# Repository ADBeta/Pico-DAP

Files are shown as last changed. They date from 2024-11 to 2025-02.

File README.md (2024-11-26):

# Pico-DAP
Pico-DAP is a CMSIS-DAP and Virtual COM Port (VCP) Device for programming
ARM based Microcontrollers, based on the `RP2040` Raspberry Pi Pico 
architecture, using the Pico-SDK toolchain.  

This reason for this project is to perfect the CMSIS-DAP device handling for
one specific device, without the worry of porting in the future.  
The project is open to the community and any ideas you have.  

## Flashing
`pico-dap.bin` and `pico-dap.uf2` files are available in the 
[Binaries](/Firmware/bins) directory.  
Use the `.uf2` if you are flashing via USB bootloader, or `.bin` if you are 
flashing via SWD.

## PCBs
### Pico-DAP-Zero
The original PCB for this project, using an aftermarket Pico Zero Development
board  
<div style="display: flex; align-items: center; gap: 10px;">
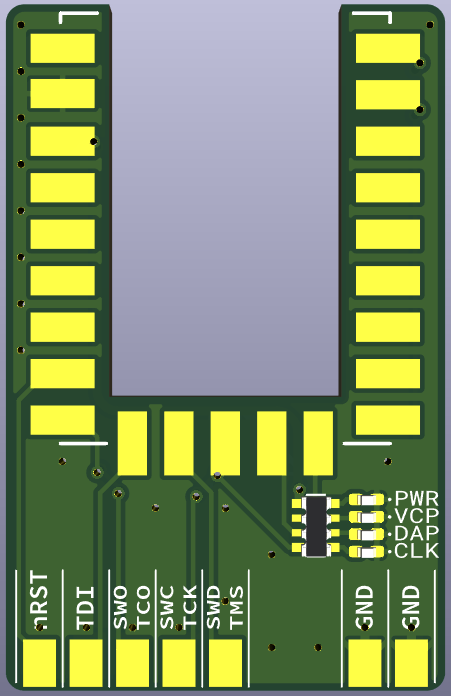
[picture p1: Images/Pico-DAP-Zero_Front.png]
Pico-DAP-Zero_Front
  
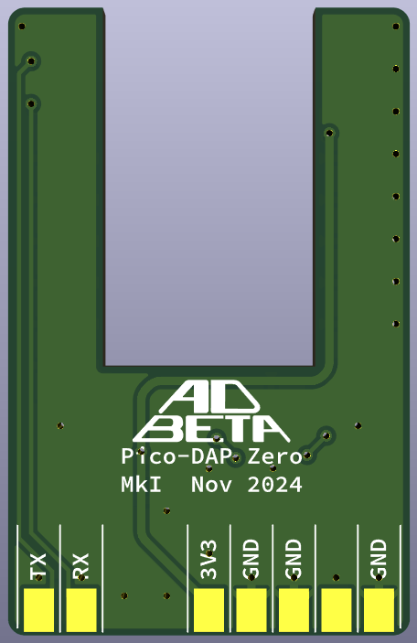
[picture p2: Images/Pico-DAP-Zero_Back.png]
Pico-DAP-Zero_Back
  
</div>

## TODO
* Move free-dap to a Pico-SDK Project
* Make a PCB for the regular Pico
* Make a PCB for a bare RP2040
* Change USB VID and PID

## Possible Changes
* Add CH32V SWIO Support
* Make specific JTAG USB Adatper

----
ADBeta (c) 2024

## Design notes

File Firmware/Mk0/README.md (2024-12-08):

# Original Firmware
This firmware is based on [free-dap](https://github.com/ataradov/free-dap), 
written by [Alex Taradov](https://github.com/ataradov).  

The only modifications made are:  
* Change VCP and DAP Status LED Pins
* Change USB Descriptor strings
* Changed Makefile to produce `pico-dap` files instead of `free-dap`

## Compilation
```sh
cd ./make
make
```
`pico-dap.uf2`and `pico-dap.bin` should be in the `/make/build/` directory

## Note
I plan on porting this firmware to be fully compatable with the Pico-SDK
for easier compilation and community modification in the near future.  
This README will be updated as progress is made

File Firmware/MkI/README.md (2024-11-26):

# Pico-DAP Firmware
This firmware is based on [free-dap](https://github.com/ataradov/free-dap), 
written by [Alex Taradov](https://github.com/ataradov).  
Converted into a Pico-SDK Project, with changes and improvements.

## Binary files
`pico-dap.bin` and `pico-dap.uf2` are available in the [Binary](/Firmware/bins) 
directory for easy installation.

## Compilation
You will need to install [Pico-SDK](https://www.raspberrypi.com/documentation/microcontrollers/c_sdk.html)
and Optionally [picotool](https://github.com/raspberrypi/picotool) in order to compile this firmware.  
```sh
mkdir ./build
cd ./build
cmake ..
make
```
`pico-dap.bin` and `pico-dap.uf2` files should now be in the `build` directroy

## Changelog
* Changed USB Device Descriptors
* Changed VID PID for USB
* Changed VCP and DAP Status LEDs

## TODO
### HIGH PRIORITY
* Convert all IO Calls to remove hal files
* Convert all uart calls to remove uart.c/.h
* Convert fully from rp2040.h to pico-stdlib

### MEDIUM PRIORITY
* make tasks.c/.h to tidy up main task handing

### LOW PRIORITY

----
ADBeta (c) 2024

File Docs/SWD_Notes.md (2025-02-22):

# CMSIS-DAP / DAP / SWD notes

## Nodes
Communication is over one generic bus : DAP `Debug Access Port`  
Master device is DP `Debug Port`  
Slave Device(s) are AP `Access Ports`  
Packets are sent from the `DP` to the `AP`. The Packets contain the Address  

Comms can be done over `JTAG`, `AHB` and `APB`:
* JTAG
* AHB
* APB

## Port types
* JTAG     (Uses JTAG Protocol)
* SW-DP    (Uses SWD specifically)
* SWJ-DP   (Uses JTAG Or SWD)

Memory access and JTAG access are possible depending on need

## Hardware Protocol
- SWCLK - Max 60MHz clock signal
- SwDIO - Bidirectional data signal - SET by `DP` on Rising Edge, Read by `DP` on falling edge
```
RQST Phase:    8 bit          [Start (1)] [AP(1)/DP(0)] [R(1)/W(0)] [AP/DP ADDR][AP/DP ADDR] [Odd Parity] [Stop (0)] [Park (1)]
ACK Phase:     3 bit          [OK]  [WAIT (Retry)] [FAULT]
DATA Phase:    32 bit         LSB First
PARITY:        1 bit odd

Extra Trn clock cycle when DDR Changes
```

## Registers
```
0x00

0x04    CTRL/STAT
0x0C    RDBUFF
```

## Init Procedure
**Switching from JTAG to DAP**  
1) Send 50 CLK Cycles with SWDIO HIGH
2) Send 16-bit JTAG->SWD Sequence
3) Send 50 CLK Cycles with SWDIO HIGH
`0b0111 1001 1110 0111`

**Read Debug Identity**  
Read Register 0x00 on DP  
`0xA5` `0x00000000 READ`

**Power up Debug Domain**  
Set CDBGRSTREQ and CDBGRSTACK Bits in CTRL/STAT Address  
`0x81` `0x1E000000 WRITE` NOTE: Why is this 1E when bit 28 29 set????

## Read from AP
`DP (master)` must send 

## Function Ideas
Init function sends multiple bytes of 0xFF

Struct packed with bit structure
read/write functions are calls to a generic backend function
Functions return ack bits as an enum type

## DAP HID Protocol
### Commands
```
0x00    DAP_Info                Requests ID from the DAP Device
0x01    DAP_HostStatus          Sets the host status (e.g., LED indicators)
0x02    DAP_Connect             Connects to the debug target (SWD or JTAG)
0x03    DAP_Disconnect          Disconnects from the debug target
0x04    DAP_TransferConfigure   Configures SWD/JTAG transfer settings
0x05    DAP_Transfer            Performs a single or multiple SWD/JTAG transfers
0x06    DAP_TransferBlock       Performs a block transfer over SWD/JTAG
0x07    DAP_TransferAbort       Aborts an ongoing SWD/JTAG transfer
0x08    DAP_WriteABORT          Writes to the Debug Port (DP) Abort register
0x09    DAP_Delay               Inserts a delay (in microseconds)

0x12	DAP_SWO_Transport       Selects SWO transport protocol
0x13	DAP_SWO_Mode            Configures the SWO mode
0x14	DAP_SWO_Baudrate        Sets the SWO baud rate
0x15	DAP_SWO_Control         Controls SWO trace capture
0x16	DAP_SWO_Status          Gets the status of SWO trace

0x0A    DAP_ResetTarget         Asserts a hardware reset on the target
0x0B    DAP_SWJ_Pins            Controls SWD/JTAG pins
0x0C    DAP_SWJ_Clock           Sets the SWD/JTAG clock frequency
0x0D    DAP_SWJ_Sequence        Sends a sequence of SWD/JTAG bits
0x0E    DAP_SWD_Configure       Configures the SWD interface
0x0F    DAP_JTAG_Sequence       Sends JTAG scan chain sequences
0x10    DAP_JTAG_Configure      Configures JTAG scan chain settings
0x11    DAP_JTAG_IDCODE         Reads the JTAG IDCODE

0x17    DAP_SWO_CaptureStart    Starts SWO trace capture
0x18    DAP_SWO_CaptureStop     Stops SWO trace capture
0x19    DAP_SWO_Read            Reads available SWO trace data

0xFF    DAP_Unknown             Placeholder for unknown or invalid command
```

----
ADBeta (c) 2025

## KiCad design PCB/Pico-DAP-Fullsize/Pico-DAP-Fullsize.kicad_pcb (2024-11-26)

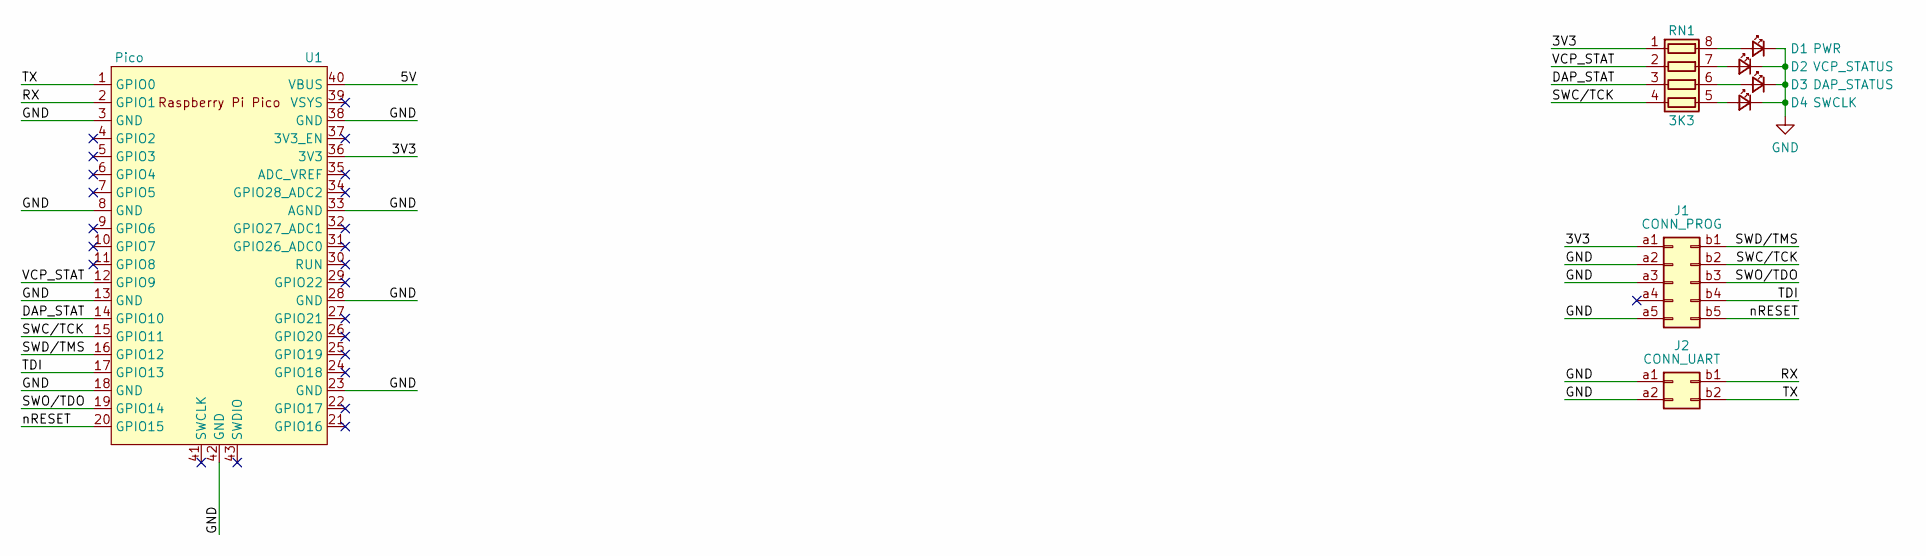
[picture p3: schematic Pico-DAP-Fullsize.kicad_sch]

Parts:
D1: PWR; LED_0402_1005Metric_Pad0.77x0.64mm_HandSolder
D2: VCP_STATUS; LED_0402_1005Metric_Pad0.77x0.64mm_HandSolder
D3: DAP_STATUS; LED_0402_1005Metric_Pad0.77x0.64mm_HandSolder
D4: SWCLK; LED_0402_1005Metric_Pad0.77x0.64mm_HandSolder
J1: CONN_PROG; Conn_2x5_Dual_Side
J2: CONN_UART; Conn_2x2_Dual_Side
RN1: 3K3; R_Array_Convex_4x0603
U1: Pico; RPi_Pico_SMD_TH

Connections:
/3V3: J1.a1, RN1.1 (R1.1), U1.36 (3V3)
/5V: U1.40 (VBUS)
/DAP_STAT: RN1.3 (R3.1), U1.14 (GPIO10)
/RX: J2.b1, U1.2 (GPIO1)
/SWC/TCK: J1.b2, RN1.4 (R4.1), U1.15 (GPIO11)
/SWD/TMS: J1.b1, U1.16 (GPIO12)
/SWO/TDO: J1.b3, U1.19 (GPIO14)
/TDI: J1.b4, U1.17 (GPIO13)
/TX: J2.b2, U1.1 (GPIO0)
/VCP_STAT: RN1.2 (R2.1), U1.12 (GPIO9)
/nRESET: J1.b5, U1.20 (GPIO15)
GND: D1.1 (K), D2.1 (K), D3.1 (K), D4.1 (K), J1.a2, J1.a3, J1.a5, J2.a1, J2.a2, U1.3 (GND), U1.8 (GND), U1.13 (GND), U1.18 (GND), U1.23 (GND), U1.28 (GND), U1.33 (AGND), U1.38 (GND), U1.42 (GND)
unnamed: D1.2 (A), RN1.8 (R1.2)
unnamed: D2.2 (A), RN1.7 (R2.2)
unnamed: D3.2 (A), RN1.6 (R3.2)
unnamed: D4.2 (A), RN1.5 (R4.2)

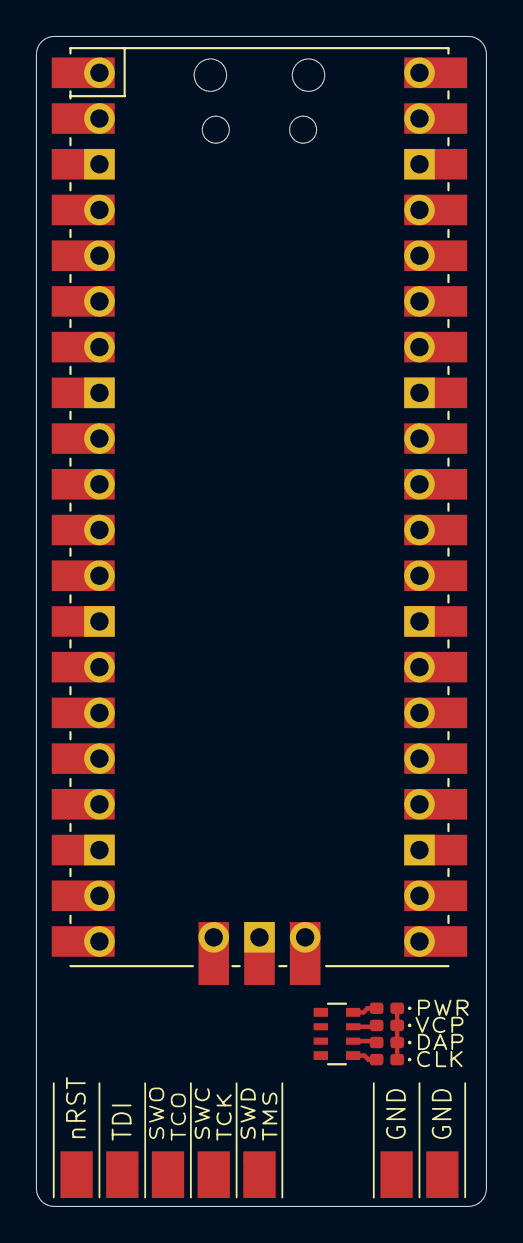
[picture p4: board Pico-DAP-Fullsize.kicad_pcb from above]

Board: 2 copper layers, 25.0 x 65.0 mm, 8 parts (1 on the bottom side), 15 nets.

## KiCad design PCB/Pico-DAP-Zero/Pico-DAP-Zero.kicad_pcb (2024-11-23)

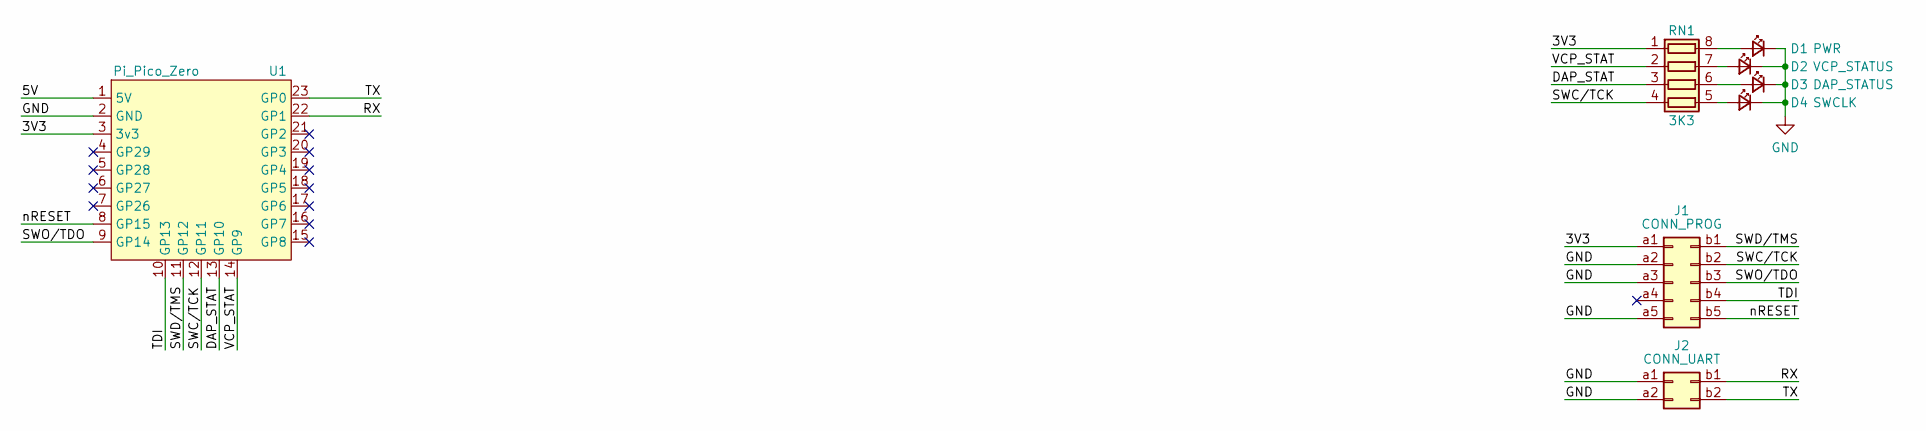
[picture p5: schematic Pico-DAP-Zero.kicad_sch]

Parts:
D1: PWR; LED_0402_1005Metric_Pad0.77x0.64mm_HandSolder
D2: VCP_STATUS; LED_0402_1005Metric_Pad0.77x0.64mm_HandSolder
D3: DAP_STATUS; LED_0402_1005Metric_Pad0.77x0.64mm_HandSolder
D4: SWCLK; LED_0402_1005Metric_Pad0.77x0.64mm_HandSolder
J1: CONN_PROG; Conn_2x5_Dual_Side
J2: CONN_UART; Conn_2x2_Dual_Side
RN1: 3K3; R_Array_Convex_4x0603
U1: Pi_Pico_Zero; Pi_Pico_Zero_Center_Hole

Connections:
/3V3: J1.a1, RN1.1 (R1.1), U1.3 (3v3)
/5V: U1.1 (5V)
/DAP_STAT: RN1.3 (R3.1), U1.13 (GP10)
/RX: J2.b1, U1.22 (GP1)
/SWC/TCK: J1.b2, RN1.4 (R4.1), U1.12 (GP11)
/SWD/TMS: J1.b1, U1.11 (GP12)
/SWO/TDO: J1.b3, U1.9 (GP14)
/TDI: J1.b4, U1.10 (GP13)
/TX: J2.b2, U1.23 (GP0)
/VCP_STAT: RN1.2 (R2.1), U1.14 (GP9)
/nRESET: J1.b5, U1.8 (GP15)
GND: D1.1 (K), D2.1 (K), D3.1 (K), D4.1 (K), J1.a2, J1.a3, J1.a5, J2.a1, J2.a2, U1.2 (GND)
unnamed: D1.2 (A), RN1.8 (R1.2)
unnamed: D2.2 (A), RN1.7 (R2.2)
unnamed: D3.2 (A), RN1.6 (R3.2)
unnamed: D4.2 (A), RN1.5 (R4.2)

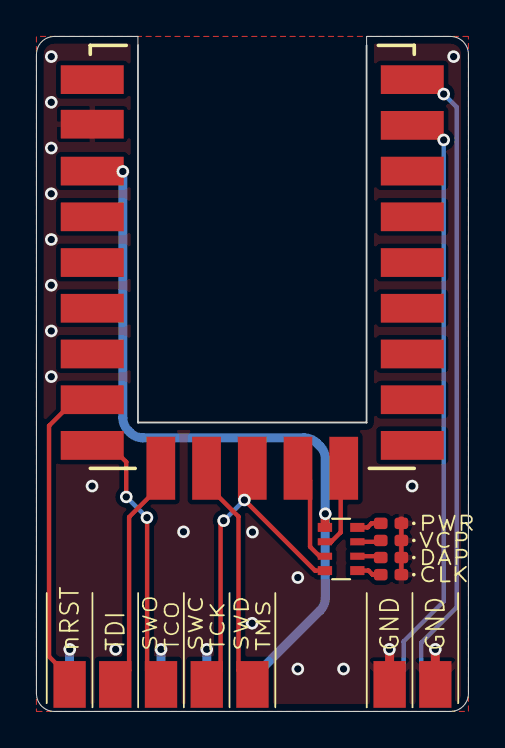
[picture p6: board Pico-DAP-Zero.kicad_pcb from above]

Board: 2 copper layers, 24.0 x 37.5 mm, 8 parts (1 on the bottom side), 15 nets.

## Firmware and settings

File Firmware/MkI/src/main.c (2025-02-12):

/******************************************************************************
* Pico-DAP MkI
* Raspberry Pi Pico based CMSIS-DAP and UART Combo USB Device
* Based on the principals of free-dap:
* 	Copyright (c) 2022, Alex Taradov <alex@taradov.com>. All rights reserved.
*
* Pico-DAP is a total rewrite, focussing on the RP2040 Chip, 
* i.e Raspberry Pi Pico:
* 	Copyright (c) 2025, ADBeta
*
* Any parts of Pico-DAP used directly from free-dap will retain their original
* Copyright strings.
*
* 10 Feb 2025    V0.2.0
******************************************************************************/
#include <stdlib.h>
#include <stdint.h>
#include <stdbool.h>
#include <string.h>




#include "pico/stdlib.h"
#include "hardware/clocks.h"
#include "hardware/pll.h"
#include "hardware/uart.h"

#include "pin_config.h"

#include "bsp/board_api.h"
#include "tusb.h"

/*** Definitions *************************************************************/
// UART and CDC Buffer Size - The Hardware UART FIFO is 32Bytes, so this is 
// the limiting factor - could add a UART IRQ and a Ring Buffer if needed.
#define CDC_BUFFER_SIZE    64
#define UART_BUFFER_SIZE   64

// Timing Millisecond Values
#define MILLIS_USB         10
#define MILLIS_LED         500

/*** Enums and Types *********************************************************/


/*** Globals *****************************************************************/
// Current Milliseconds - Updated by a systick
volatile uint32_t g_current_millis = 0;

/*** Function Declarations ***************************************************/
/// @brief USB CDC Task that run in an infinite loop - pushes data back and 
/// forth from CDC to UART
/// @param None
/// @return None
void cdc_uart_task(void);

/// @brief Handles the LEDs based on system status
/// @param None
/// @return None
void led_task(void);





/*** Callback Functions ******************************************************/
/// @brief Sets the UART baudrate dependinging on what thr USB CDC Device
/// requested
void tud_cdc_line_coding_cb(uint8_t itf, cdc_line_coding_t const* p_line_coding) 
{
	uart_set_baudrate(PERIPH_UART_ID, p_line_coding->bit_rate);
}


/// @breif ticks once per Millisecond and incriments the global counter
bool ms_timer_callback(__unused struct repeating_timer *t)
{
	g_current_millis++;
	return true;
}



/*** Function Declarations ***************************************************/
/// @brief Initalises the GPIO modes, startup states, etc
/// @param None
/// @return None
static void gpio_setup(void);


/*** Main ********************************************************************/
int main(void)
{
	// Set up a 1ms timer
	struct repeating_timer ms_timer;
    add_repeating_timer_ms(1, ms_timer_callback, NULL, &ms_timer);
	
	// TinyUSB Setup - Config the USB Handler to the Board, then initialise
	// the TinyUSB system
	board_init();
	tud_init(BOARD_TUD_RHPORT);


	// TODO: HID Init???

	// Initialise the LED and UART GPIO
	gpio_setup();

	// Initialise the UART Hardware
	uart_init(PERIPH_UART_ID, 9600);                                           // Initialise the UART Peripheral with a basic baudrate
	uart_set_hw_flow(PERIPH_UART_ID, false, false);                            // Disable flow control
	uart_set_format(PERIPH_UART_ID, 8, 1, UART_PARITY_NONE);                   // Set Data its, Stop Bits and ParityUART_PARITY_NONE
	uart_set_fifo_enabled(PERIPH_UART_ID, true);                               // Enable FIFO buffering of UART



	// Loop Timing Variables
	static uint32_t prev_usb_millis = 0;
	static uint32_t prev_led_millis = 0;

	// Start Infinite loop
	while(true)
	{

		if(g_current_millis - prev_usb_millis > MILLIS_USB)
		{
			tud_task();
			cdc_uart_task();
			prev_usb_millis = g_current_millis;
		}


		if(g_current_millis - prev_led_millis > MILLIS_LED)
		{
			led_task();
			prev_led_millis = g_current_millis;
		}
		
	} // End Inifinite loop



	/*
	while(1)
	{
		sys_time_task();
		usb_task();
		tx_task();
		rx_task();
		break_task();
		uart_timer_task();
		status_timer_task();
	}

	*/



	return 0;
}

/*** Function Definitions ****************************************************/
static void gpio_setup(void)
{
	gpio_init(PIN_LED_TEST);
	gpio_init(PIN_LED_UART);
	gpio_init(PIN_LED_DAP);

	gpio_set_dir(PIN_LED_TEST, GPIO_OUT);
	gpio_set_dir(PIN_LED_UART, GPIO_OUT);
	gpio_set_dir(PIN_LED_DAP, GPIO_OUT);

	// Set UART Pins
	gpio_set_function(PIN_UART_TX, UART_FUNCSEL_NUM(PERIPH_UART_ID, PIN_UART_TX));
	gpio_set_function(PIN_UART_RX, UART_FUNCSEL_NUM(PERIPH_UART_ID, PIN_UART_RX));
}


void cdc_uart_task(void)
{
	static uint8_t cdc_buff[CDC_BUFFER_SIZE];
	static uint8_t uart_buff[UART_BUFFER_SIZE];
	// If data is available in the UART, pull it into the buffer, then
	// push it out to the CDC Device
	size_t uart_bytes = 0;
	while(uart_is_readable(PERIPH_UART_ID) && (uart_bytes < UART_BUFFER_SIZE))
	{
		uart_buff[uart_bytes] = (uint8_t)uart_getc(PERIPH_UART_ID);
		uart_bytes++;
	}
	tud_cdc_write(uart_buff, uart_bytes);
	tud_cdc_write_flush();


	// If data is available in the CDC Buffer, push it to the UART
	size_t cdc_bytes = 0;
	if(tud_cdc_available() && (cdc_bytes = tud_cdc_read(cdc_buff, CDC_BUFFER_SIZE)))
	{
		uart_write_blocking(PERIPH_UART_ID, cdc_buff, cdc_bytes);
	}
}


void led_task(void)
{
	// Lights the UART LED if the CDC Device is connected
	// NOTE: Relies on the RING signal when connecting
	gpio_put(PIN_LED_UAR, tud_cdc_connected());
}









/*** OLD CODE *******
pio_set_function(0, UART_FUNCSEL_NUM(uart0, 0));
gpio_set_function(1, UART_FUNCSEL_NUM(uart0, 1));

// Initialise UART 0
uart_init(uart0, 115200);

- Definitions -------------------------------------------------------------
#define USB_BUFFER_SIZE        64
#define UART_WAIT_TIMEOUT      10 // ms
#define STATUS_TIMEOUT         250 // ms

#define F_REF          12000000
#define F_CPU          120000000
#define F_PER          120000000
#define F_RTC          (F_REF / 256)
#define F_TICK         1000000

- Variables ---------------------------------------------------------------
static uint8_t app_req_buf_hid[DAP_CONFIG_PACKET_SIZE];
static uint8_t app_resp_buf_hid[DAP_CONFIG_PACKET_SIZE];
static uint8_t app_req_buf_bulk[DAP_CONFIG_PACKET_SIZE];
static uint8_t app_resp_buf_bulk[DAP_CONFIG_PACKET_SIZE];
static uint8_t app_recv_buffer[USB_BUFFER_SIZE];
static uint8_t app_send_buffer[USB_BUFFER_SIZE];
static int app_recv_buffer_size = 0;
static int app_recv_buffer_ptr = 0;
static int app_send_buffer_ptr = 0;
static bool app_send_buffer_free = true;
static bool app_send_zlp = false;
static uint64_t app_system_time = 0;
static uint64_t app_uart_timeout = 0;
static uint64_t app_status_timeout = 0;
static uint64_t app_break_timeout = 0;
static bool app_dap_event = false;
static bool app_vcp_event = false;
static bool app_vcp_open = false;

- Implementations ---------------------------------------------------------

//-----------------------------------------------------------------------------
static void sys_init(void)
{
  // Enable XOSC
  XOSC->CTRL     = (XOSC_CTRL_FREQ_RANGE_1_15MHZ << XOSC_CTRL_FREQ_RANGE_Pos);
  XOSC->STARTUP  = 47; // ~1 ms @ 12 MHz
  XOSC_SET->CTRL = (XOSC_CTRL_ENABLE_ENABLE << XOSC_CTRL_ENABLE_Pos);
  while (0 == (XOSC->STATUS & XOSC_STATUS_STABLE_Msk));

  // Setup SYS PLL for 12 MHz * 40 / 4 / 1 = 120 MHz
  RESETS_CLR->RESET = RESETS_RESET_pll_sys_Msk;
  while (0 == RESETS->RESET_DONE_b.pll_sys);

  PLL_SYS->CS = (1 << PLL_SYS_CS_REFDIV_Pos);
  PLL_SYS->FBDIV_INT = 40;
  PLL_SYS->PRIM = (4 << PLL_SYS_PRIM_POSTDIV1_Pos) | (1 << PLL_SYS_PRIM_POSTDIV2_Pos);

  PLL_SYS_CLR->PWR = PLL_SYS_PWR_VCOPD_Msk | PLL_SYS_PWR_PD_Msk;
  while (0 == PLL_SYS->CS_b.LOCK);

  PLL_SYS_CLR->PWR = PLL_SYS_PWR_POSTDIVPD_Msk;

  // Setup USB PLL for 12 MHz * 36 / 3 / 3 = 48 MHz
  RESETS_CLR->RESET = RESETS_RESET_pll_usb_Msk;
  while (0 == RESETS->RESET_DONE_b.pll_usb);

  PLL_USB->CS = (1 << PLL_SYS_CS_REFDIV_Pos);
  PLL_USB->FBDIV_INT = 36;
  PLL_USB->PRIM = (3 << PLL_SYS_PRIM_POSTDIV1_Pos) | (3 << PLL_SYS_PRIM_POSTDIV2_Pos);

  PLL_USB_CLR->PWR = PLL_SYS_PWR_VCOPD_Msk | PLL_SYS_PWR_PD_Msk;
  while (0 == PLL_USB->CS_b.LOCK);

  PLL_USB_CLR->PWR = PLL_SYS_PWR_POSTDIVPD_Msk;

  // Switch clocks to their final socurces
  CLOCKS->CLK_REF_CTRL = (CLOCKS_CLK_REF_CTRL_SRC_xosc_clksrc << CLOCKS_CLK_REF_CTRL_SRC_Pos);

  CLOCKS->CLK_SYS_CTRL = (CLOCKS_CLK_SYS_CTRL_AUXSRC_clksrc_pll_sys << CLOCKS_CLK_SYS_CTRL_AUXSRC_Pos);
  CLOCKS_SET->CLK_SYS_CTRL = (CLOCKS_CLK_SYS_CTRL_SRC_clksrc_clk_sys_aux << CLOCKS_CLK_SYS_CTRL_SRC_Pos);

  CLOCKS->CLK_PERI_CTRL = CLOCKS_CLK_PERI_CTRL_ENABLE_Msk |
      (CLOCKS_CLK_PERI_CTRL_AUXSRC_clk_sys << CLOCKS_CLK_PERI_CTRL_AUXSRC_Pos);

  CLOCKS->CLK_USB_CTRL = CLOCKS_CLK_USB_CTRL_ENABLE_Msk |
      (CLOCKS_CLK_USB_CTRL_AUXSRC_clksrc_pll_usb << CLOCKS_CLK_USB_CTRL_AUXSRC_Pos);

  CLOCKS->CLK_ADC_CTRL = CLOCKS_CLK_ADC_CTRL_ENABLE_Msk |
      (CLOCKS_CLK_ADC_CTRL_AUXSRC_clksrc_pll_usb << CLOCKS_CLK_ADC_CTRL_AUXSRC_Pos);

  CLOCKS->CLK_RTC_DIV = (256 << CLOCKS_CLK_RTC_DIV_INT_Pos); // 12MHz / 256 = 46875 Hz
  CLOCKS->CLK_RTC_CTRL = CLOCKS_CLK_RTC_CTRL_ENABLE_Msk |
      (CLOCKS_CLK_RTC_CTRL_AUXSRC_xosc_clksrc << CLOCKS_CLK_ADC_CTRL_AUXSRC_Pos);

  // Configure 1 us tick for watchdog and timer
  WATCHDOG->TICK = ((F_REF/F_TICK) << WATCHDOG_TICK_CYCLES_Pos) | WATCHDOG_TICK_ENABLE_Msk;

  // Enable GPIOs
  RESETS_CLR->RESET = RESETS_RESET_io_bank0_Msk | RESETS_RESET_pads_bank0_Msk;
  while (0 == RESETS->RESET_DONE_b.io_bank0 || 0 == RESETS->RESET_DONE_b.pads_bank0);
}

//-----------------------------------------------------------------------------
static void serial_number_init(void)
{
  volatile uint8_t *uid = (volatile uint8_t *)0x20041f01;
  uint32_t sn = 5381;

  for (int i = 0; i < 16; i++)
    sn = ((sn << 5) + sn) ^ uid[i];

  for (int i = 0; i < 8; i++)
    usb_serial_number[i] = "0123456789ABCDEF"[(sn >> (i * 4)) & 0xf];

  usb_serial_number[8] = 0;
}

//-----------------------------------------------------------------------------
static void sys_time_init(void)
{
  SysTick->VAL  = 0;
  SysTick->LOAD = 1000; // 1 ms
  SysTick->CTRL = SysTick_CTRL_ENABLE_Msk;
  app_system_time = 0;
}

//-----------------------------------------------------------------------------
static void sys_time_task(void)
{
  if (SysTick->CTRL & SysTick_CTRL_COUNTFLAG_Msk)
    app_system_time++;
}

//-----------------------------------------------------------------------------
static void tx_task(void)
{
  while (app_recv_buffer_size)
  {
    if (!uart_write_byte(app_recv_buffer[app_recv_buffer_ptr]))
      break;

    app_recv_buffer_ptr++;
    app_recv_buffer_size--;
    app_vcp_event = true;

    if (0 == app_recv_buffer_size)
      usb_cdc_recv(app_recv_buffer, sizeof(app_recv_buffer));
  }
}

//-----------------------------------------------------------------------------
static void send_buffer(void)
{
  app_send_buffer_free = false;
  app_send_zlp = (USB_BUFFER_SIZE == app_send_buffer_ptr);

  usb_cdc_send(app_send_buffer, app_send_buffer_ptr);

  app_send_buffer_ptr = 0;
}

//-----------------------------------------------------------------------------
static void rx_task(void)
{
  int byte;

  if (!app_send_buffer_free)
    return;

  while (uart_read_byte(&byte))
  {
    int state = (byte >> 8) & 0xff;

    app_uart_timeout = app_system_time + UART_WAIT_TIMEOUT;
    app_vcp_event = true;

    if (state)
    {
      usb_cdc_set_state(state);
    }
    else
    {
      app_send_buffer[app_send_buffer_ptr++] = byte;

      if (USB_BUFFER_SIZE == app_send_buffer_ptr)
      {
        send_buffer();
        break;
      }
    }
  }
}

//-----------------------------------------------------------------------------
static void break_task(void)
{
  if (app_break_timeout && app_system_time > app_break_timeout)
  {
    raw_uart_set_break(false);
    app_break_timeout = 0;
  }
}

//-----------------------------------------------------------------------------
static void uart_timer_task(void)
{
  if (app_uart_timeout && app_system_time > app_uart_timeout)
  {
    if (app_send_zlp || app_send_buffer_ptr)
      send_buffer();

    app_uart_timeout = 0;
  }
}

//-----------------------------------------------------------------------------
void usb_cdc_line_coding_updated(usb_cdc_line_coding_t *line_coding)
{
  raw_uart_init(line_coding);
}

//-----------------------------------------------------------------------------
void usb_cdc_control_line_state_update(int line_state)
{
  bool status = line_state & USB_CDC_CTRL_SIGNAL_DTE_PRESENT;

  app_vcp_open        = status;
  app_send_buffer_ptr = 0;
  app_uart_timeout    = 0;
  app_break_timeout   = 0;

  if (app_vcp_open)
    raw_uart_init(usb_cdc_get_line_coding());
  else
    uart_close();
}

//-----------------------------------------------------------------------------
void usb_cdc_send_break(int duration)
{
  if (USB_CDC_BREAK_DURATION_DISABLE == duration)
  {
    app_break_timeout = 0;
    raw_uart_set_break(false);
  }
  else if (USB_CDC_BREAK_DURATION_INFINITE == duration)
  {
    app_break_timeout = 0;
    raw_uart_set_break(true);
  }
  else
  {
    app_break_timeout = app_system_time + duration;
    raw_uart_set_break(true);
  }
}

//-----------------------------------------------------------------------------
void usb_cdc_send_callback(void)
{
  app_send_buffer_free = true;
}

//-----------------------------------------------------------------------------
void usb_cdc_recv_callback(int size)
{
  app_recv_buffer_ptr = 0;
  app_recv_buffer_size = size;
}

//-----------------------------------------------------------------------------
void usb_hid_send_callback(void)
{
  usb_hid_recv(app_req_buf_hid, DAP_CONFIG_PACKET_SIZE);
}

//-----------------------------------------------------------------------------
void usb_hid_recv_callback(int size)
{
  app_dap_event = true;
  dap_process_request(app_req_buf_hid, sizeof(app_req_buf_hid),
      app_resp_buf_hid, sizeof(app_resp_buf_hid));
  usb_hid_send(app_resp_buf_hid, sizeof(app_resp_buf_hid));
  (void)size;
}

//-----------------------------------------------------------------------------
static void usb_bulk_send_callback(void)
{
  usb_recv(USB_BULK_EP_RECV, app_req_buf_bulk, sizeof(app_req_buf_bulk));
}

//-----------------------------------------------------------------------------
static void usb_bulk_recv_callback(int size)
{
  app_dap_event = true;
  size = dap_process_request(app_req_buf_bulk, size,
      app_resp_buf_bulk, sizeof(app_resp_buf_bulk));
  usb_send(USB_BULK_EP_SEND, app_resp_buf_bulk, size);
}

//-----------------------------------------------------------------------------
void usb_configuration_callback(int config)
{
  usb_set_send_callback(USB_BULK_EP_SEND, usb_bulk_send_callback);
  usb_set_recv_callback(USB_BULK_EP_RECV, usb_bulk_recv_callback);

  usb_cdc_recv(app_recv_buffer, sizeof(app_recv_buffer));
  usb_hid_recv(app_req_buf_hid, sizeof(app_req_buf_hid));
  usb_recv(USB_BULK_EP_RECV, app_req_buf_bulk, sizeof(app_req_buf_bulk));

  app_send_buffer_free = true;
  app_send_buffer_ptr = 0;

  (void)config;
}

//-----------------------------------------------------------------------------
static void status_timer_task(void)
{
  if (app_system_time < app_status_timeout)
    return;

  app_status_timeout = app_system_time + STATUS_TIMEOUT;

  if (app_dap_event)
    HAL_GPIO_DAP_STATUS_toggle();
  else
    HAL_GPIO_DAP_STATUS_set();

  if (app_vcp_event)
    HAL_GPIO_VCP_STATUS_toggle();
  else
    HAL_GPIO_VCP_STATUS_write(app_vcp_open);

  app_dap_event = false;
  app_vcp_event = false;
}

//-----------------------------------------------------------------------------
int main(void)
{
  sys_init();
  sys_time_init();
  dap_init();
  usb_init();
  usb_cdc_init();
  usb_hid_init();
  serial_number_init();

  app_status_timeout = STATUS_TIMEOUT;

  HAL_GPIO_VCP_STATUS_out();
  HAL_GPIO_VCP_STATUS_clr();

  HAL_GPIO_DAP_STATUS_out();
  HAL_GPIO_DAP_STATUS_set();

  while (1)
  {
    sys_time_task();
    usb_task();
    tx_task();
    rx_task();
    break_task();
    uart_timer_task();
    status_timer_task();
  }

  return 0;
}
*/

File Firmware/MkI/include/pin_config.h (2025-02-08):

/******************************************************************************
* Pico-DAP MkI Pin Configuration
*
* (c) ADBeta 2025
******************************************************************************/
#ifndef PIN_CONFIG_H
#define PIN_CONFIG_H

#define PERIPH_UART_ID   uart0
#define PIN_UART_TX      0
#define PIN_UART_RX      1

#define PIN_LED_TEST     25
#define PIN_LED_UART     9
#define PIN_LED_DAP      10

#define PIN_SWCLK_TCK    11
#define PIN_SWDIO_TMS    12
#define PIN_TDI          13
#define PIN_TDO          14
#define PIN_nRESET       15


#endif

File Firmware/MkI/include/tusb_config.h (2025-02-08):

/*
 * USB CDC and DAP TinyUSB Descriptors Configuration file
 *
 * Part of Pico-DAP:
 *     https://github.com/ADBeta/Pico-DAP
 * (c) ADBeta 2025
 *
 * The MIT License (MIT)
 *
 * Copyright (c) 2019 Ha Thach (tinyusb.org)
 *
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
 */

#ifndef _TUSB_CONFIG_H_
#define _TUSB_CONFIG_H_

#ifdef __cplusplus
 extern "C" {
#endif

//--------------------------------------------------------------------+
// Board Specific Configuration
//--------------------------------------------------------------------+

// RHPort number used for device can be defined by board.mk, default to port 0
#ifndef BOARD_TUD_RHPORT
#define BOARD_TUD_RHPORT      0
#endif

// RHPort max operational speed can defined by board.mk
#ifndef BOARD_TUD_MAX_SPEED
#define BOARD_TUD_MAX_SPEED   OPT_MODE_DEFAULT_SPEED
#endif

//--------------------------------------------------------------------
// COMMON CONFIGURATION
//--------------------------------------------------------------------

// defined by board.mk
#ifndef CFG_TUSB_MCU
#error CFG_TUSB_MCU must be defined
#endif

#ifndef CFG_TUSB_OS
#define CFG_TUSB_OS           OPT_OS_NONE
#endif

#ifndef CFG_TUSB_DEBUG
#define CFG_TUSB_DEBUG        0
#endif

// Enable Device stack
#define CFG_TUD_ENABLED       1

// Default is max speed that hardware controller could support with on-chip PHY
#define CFG_TUD_MAX_SPEED     BOARD_TUD_MAX_SPEED

/* USB DMA on some MCUs can only access a specific SRAM region with restriction on alignment.
 * Tinyusb use follows macros to declare transferring memory so that they can be put
 * into those specific section.
 * e.g
 * - CFG_TUSB_MEM SECTION : __attribute__ (( section(".usb_ram") ))
 * - CFG_TUSB_MEM_ALIGN   : __attribute__ ((aligned(4)))
 */
#ifndef CFG_TUSB_MEM_SECTION
#define CFG_TUSB_MEM_SECTION
#endif

#ifndef CFG_TUSB_MEM_ALIGN
#define CFG_TUSB_MEM_ALIGN          __attribute__ ((aligned(4)))
#endif

//--------------------------------------------------------------------
// DEVICE CONFIGURATION
//--------------------------------------------------------------------

#ifndef CFG_TUD_ENDPOINT0_SIZE
#define CFG_TUD_ENDPOINT0_SIZE    64
#endif

//------------- CLASS -------------//
#define CFG_TUD_CDC               1
#define CFG_TUD_MSC               0
#define CFG_TUD_HID               0
#define CFG_TUD_MIDI              0
#define CFG_TUD_VENDOR            0

// CDC FIFO size of TX and RX
#define CFG_TUD_CDC_RX_BUFSIZE   (TUD_OPT_HIGH_SPEED ? 512 : 64)
#define CFG_TUD_CDC_TX_BUFSIZE   (TUD_OPT_HIGH_SPEED ? 512 : 64)

// CDC Endpoint transfer buffer size, more is faster
#define CFG_TUD_CDC_EP_BUFSIZE   (TUD_OPT_HIGH_SPEED ? 512 : 64)

#ifdef __cplusplus
 }
#endif

#endif /* _TUSB_CONFIG_H_ */

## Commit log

2024-11-20 Restructured file tree
    [Pi_Pico_Zero_CMSIS_DAP.kicad_pcb, Pi_Pico_Zero_CMSIS_DAP.kicad_sch]
2024-11-21 MkI PCB Final
    [Pi_Pico_Zero_CMSIS_DAP.kicad_pcb, Pi_Pico_Zero_CMSIS_DAP.kicad_sch]
2024-11-22 Added Firmware Original
    [pi-cmsis-dap.cfg]
2024-11-22 Changed LED Pinout
2024-11-23 Renamed PCB
    [Pico-DAP-Zero.kicad_pcb, Pico-DAP-Zero.kicad_sch]
2024-11-23 Renamed project
    [pico-dap.cfg]
2024-11-23 Changed PCB Silkscreen
    [Pico-DAP-Zero.kicad_pcb]
2024-11-26 Added fullsize PCB
    [Pico-DAP-Fullsize.kicad_pcb, Pico-DAP-Fullsize.kicad_sch]
2024-11-26 Started to remove rp2040.h and uart.h
2024-11-29 Starting UART changeover
2024-12-08 Rolled back Mk0 Files, built functional custom .uf2
    [pico-dap.cfg]
2025-01-29 Added Pin Configuration and basic UART Setup
2025-01-31 UART Testing
2025-02-08 Functional Test LED and Baudrate
2025-02-10 Changed UART LED, and set all LED GPIO Pins
